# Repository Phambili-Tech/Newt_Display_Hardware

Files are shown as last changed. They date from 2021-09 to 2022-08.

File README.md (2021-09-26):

# Newt

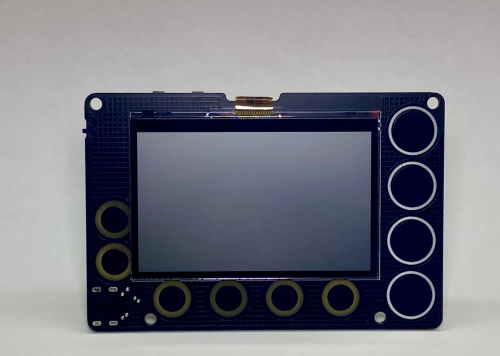
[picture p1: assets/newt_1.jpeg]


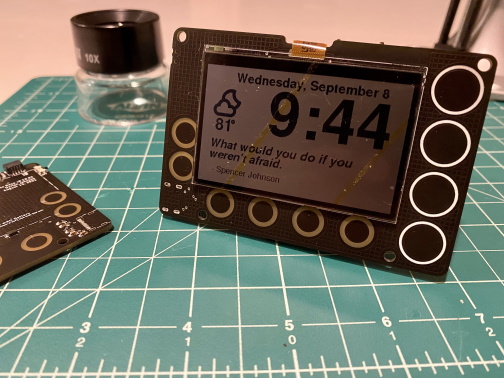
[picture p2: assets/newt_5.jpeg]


The Newt is an always-on, low-powered, mountable display that can be connected to the internet to retrieve weather, calendars, sports scores, todo lists, quotes... really anything that is available on the web! The Newt is powered by an ESP32-S2 microcontroller that can be programmed with Arduino, CircuitPython, and ESP-IDF.

We consider the Newt to be the next evolution of the popular eInk displays that makers love to tinker with. We use a SHARP Memory In Pixel LCD in order to avoid the slow refresh times of eInk. We've added a Real Time Clock to support alarms and timers. Finally, we designed the Newt with battery operation in mind;  every component on the board was chosen for it's ability to operate at low power.

**Lists of product features and/or specifications:**

The Newt is designed to operate for 1-2 months between charges (using a 500 mAH Lipo). The amount of time varies between usage; heavier WiFi usage will more quickly reduce battery charge.

Microcontroller:
- Espressif ESP32-S2-WROVER Module with 4 MB flash and 2 MB PSRAM
- WiFi capable
- Supports Arduino, CircuitPython, and ESP-IDF
- Deep Sleep current as low as 25 uA

Display:
- 2.7 inch 240x400 SHARP Memory In Pixel LCD
- Capable of delivering high-contrast, high-resolution content with ultra-low power consumption
- Reflective mode leverages ambient light to eliminate the need for a backlight

Time Keeping, Timers, and Alarms:
- Micro Crystal RV-3028-C7 Real Time Clock
- Optimized for extreme low power consumption (45 nanoAmps)
- Able to simultaneously manage periodic timer, countdown timer, and alarm
- Hardware interrupt for timers and alarms
- 43 bytes non-volatile user memory, 2 bytes user RAM
- Separate UNIX time counter

Buzzer:
- Speaker/Buzzer with mini class D amplifier on DAC output A0 can play tones or lo-fi audio clips

User Interaction:
- 10 capacitive touch pads
- On/off switch
- Reset and Boot tactile buttons for reprogramming

Power:
- USB Type-C connector for programming, power, and charging
- Low quiescence Voltage Regulator (TOREX XC6220) that can output 1A of current and operate as low as 8 uA.
- JST connector for Lithium-Ion battery
- Battery charging circuity (MCP73831)
- Low Battery indicator (1 uA quiescence current)

PCB and Display dimensions:
- 91 mm x 61mm x 9mm

Software:
- Newt hardware compatible with open-source Arduino libraries for ESP32-S2, Adafruit GFX (fonts), Adafruit Sharp Memory Display (display writing), and RTC RV-3028-C7 (rtc)
- Newt Arduino library and sample programs in progress; will be available on Githib before launch
- Newt CircuitPython libraries and registration on the roadmap (key dependency is the development of CircuitPython library for the RV-3028 real time clock)

Optional Mounting and Desktop Hardware:
- Acrylic Mounting Bracket with magnetic fixtures and expander for "flat" lithium-Ion batteries (up to 2500mAh)
- Putty for non-magnetic adhesion
- Stand for desk or nightstand (made from engineered wood)

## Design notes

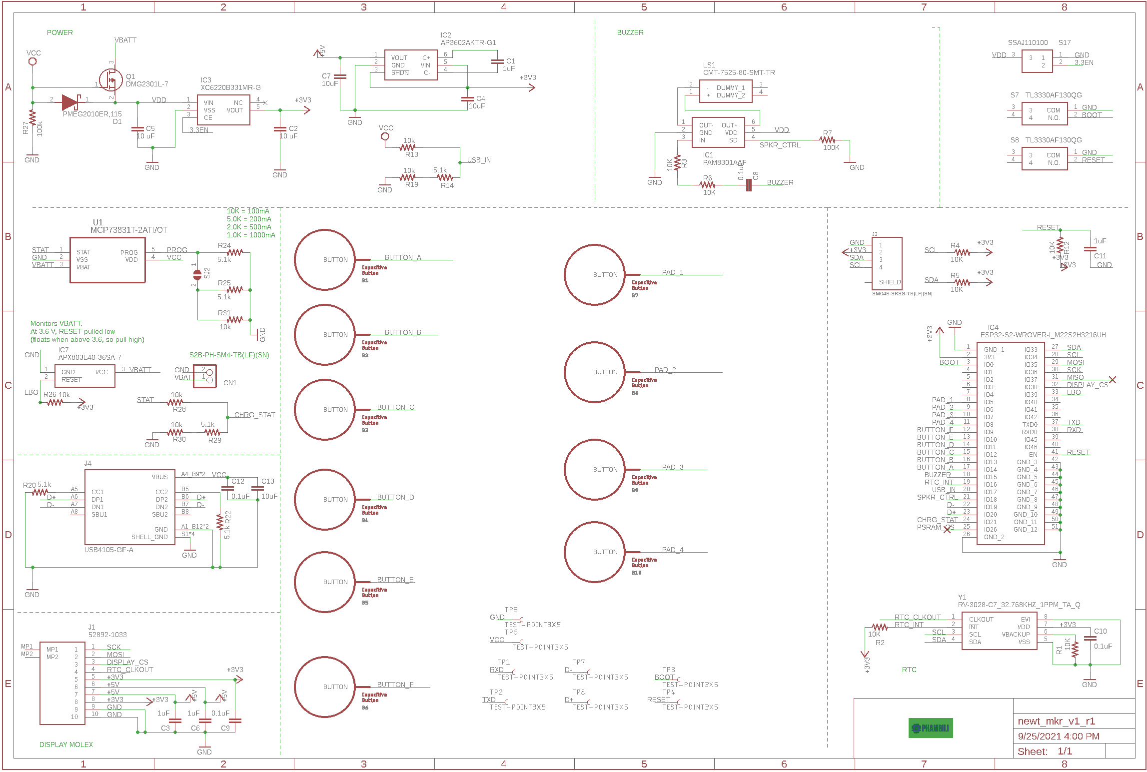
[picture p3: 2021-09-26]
schematic.png

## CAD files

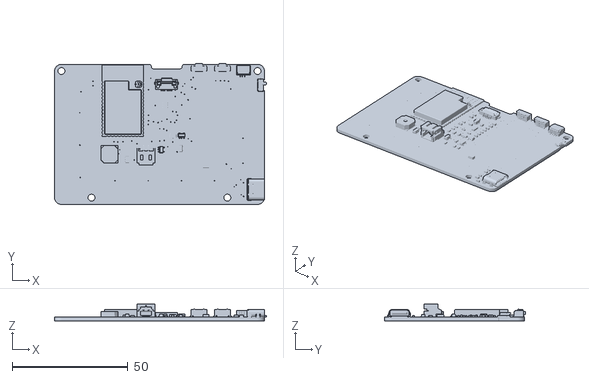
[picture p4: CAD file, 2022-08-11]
3D File Formats/Newt_v1.1_board.stl
91.7 x 60.9 x 7.17

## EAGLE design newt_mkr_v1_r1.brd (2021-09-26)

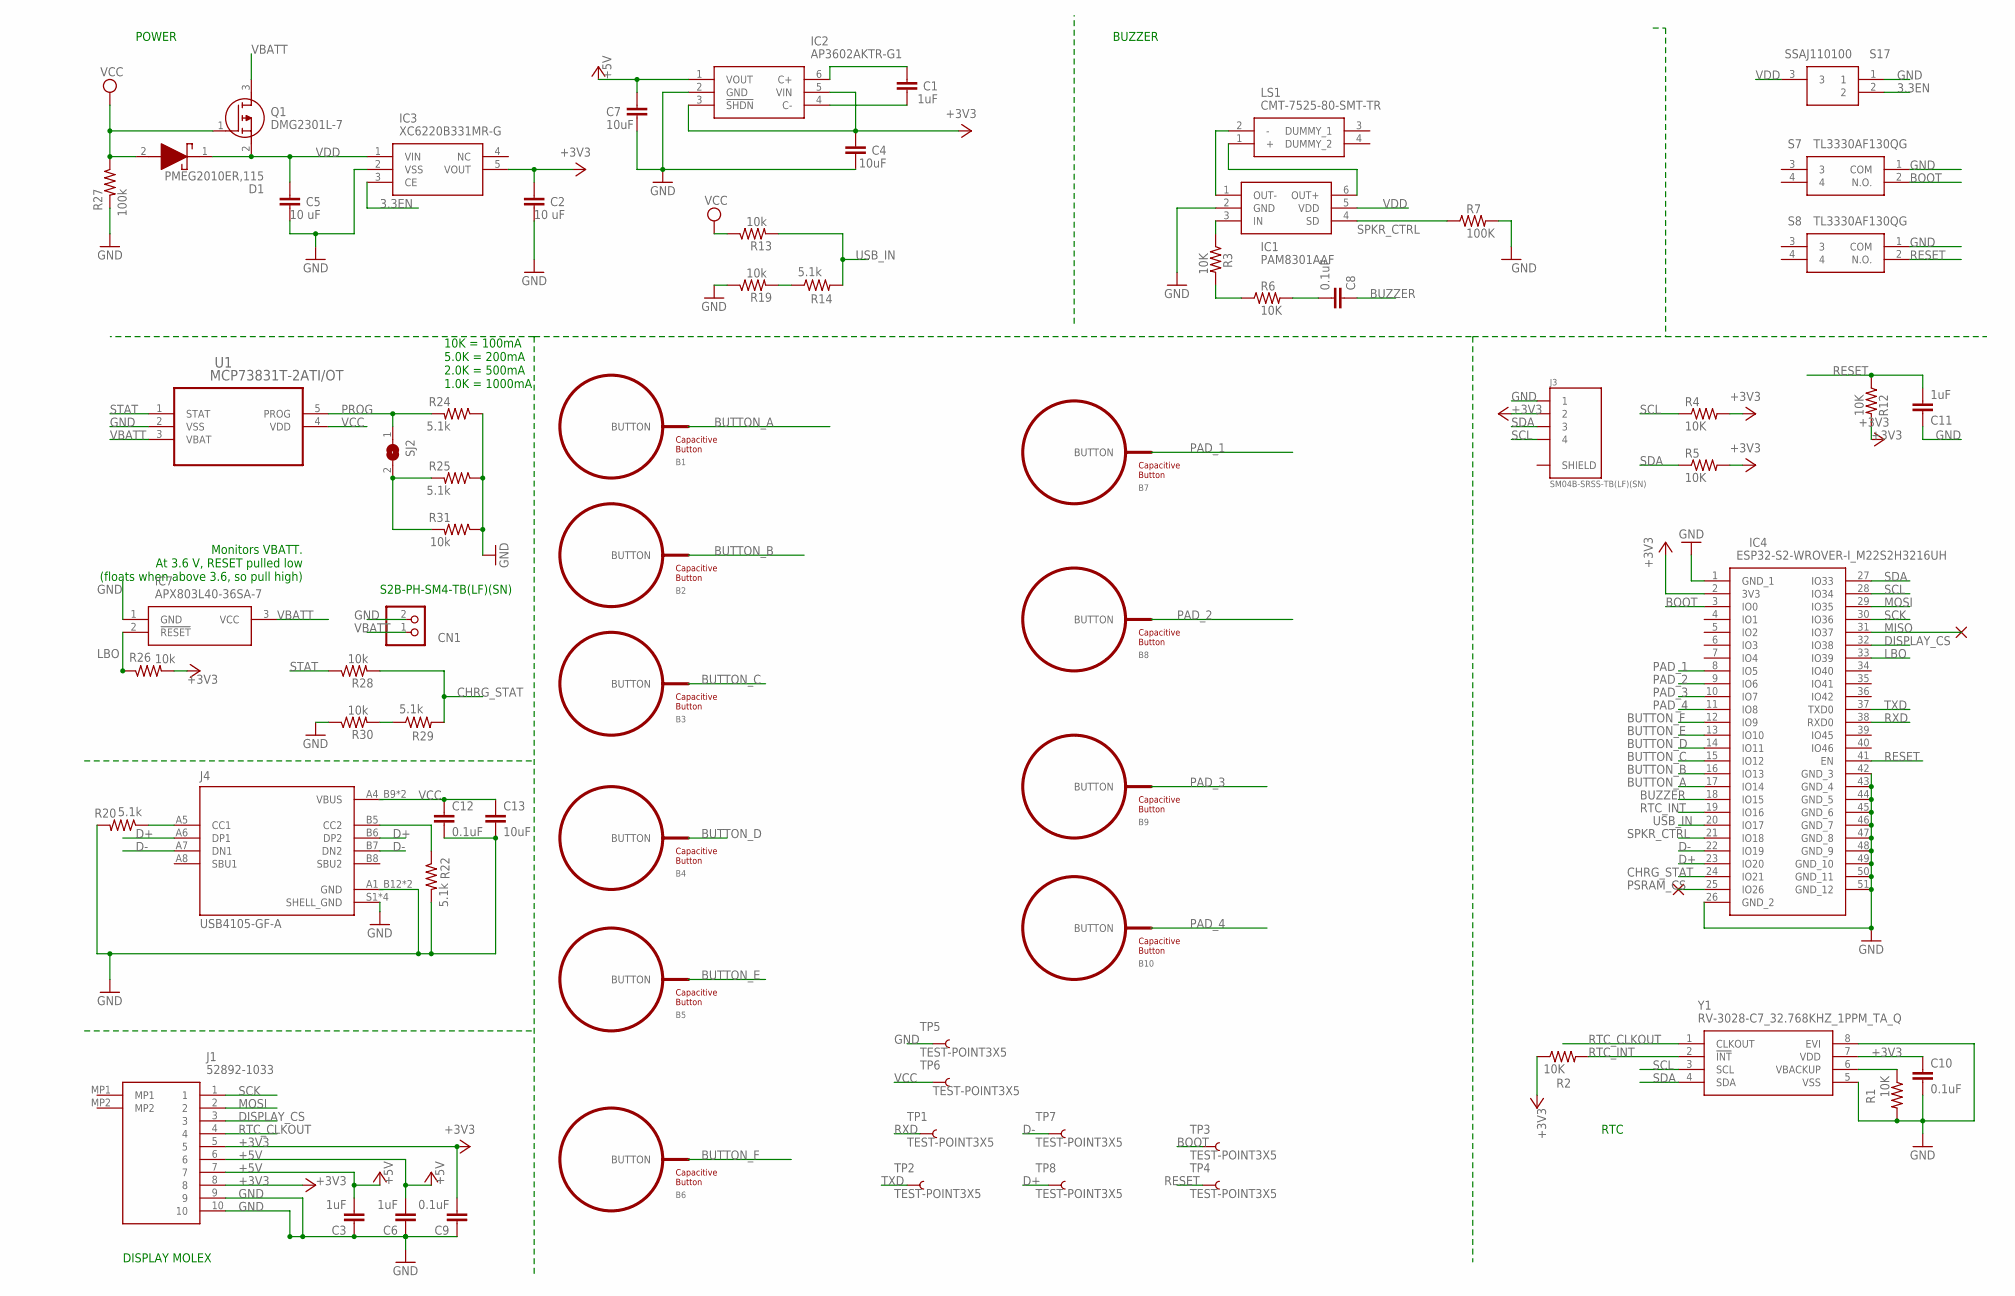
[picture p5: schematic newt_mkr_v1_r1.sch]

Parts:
B1, B2, B3, B4, B5, B6: BUTTON_PASSIVE6MM; BUTTON_PASSIVE_6MM
B7, B8, B9, B10: BUTTON_PASSIVE10MM; BUTTON_PASSIVE_10MM
C1, C3, C6, C11: 1uF; C0603
C2, C5: 10 uF; C0603
C4, C7, C13: 10uF; C0603
C8, C9, C10, C12: 0.1uF; C0603
CN1: JST_2PIN-SMT-RA; JST-PH-2-SMT-RA
D1: PMEG2010ER,115; SODFL3517X110N
IC1: PAM8301AAF; SOT95P280X145-6N
IC2: AP3602AKTR-G1; SOT95P280X145-6N
IC3: XC6220B331MR-G; SOT95P280X130-5N
IC4: ESP32-S2-WROVER-I_M22S2H3216UH; ESP32S2WROVERIM22S2H3216UH3Q0
IC7: APX803L40-36SA-7; SOT96P240X110-3N
J1: 52892-1033; 528921033
J3: SM04B-SRSS-TB(LF)(SN); JST_SM04B-SRSS-TB(LF)(SN)
J4: USB4105-GF-A; GCT_USB4105-GF-A
LS1: CMT-7525-80-SMT-TR; CMT752580SMTTR
Q1: DMG2301L-7; SOT96P240X110-3N
R1, R2, R3, R4, R5, R6, R12: 10K; R0603
R7: 100K; R0603
R13, R19, R26, R28, R30, R31: 10k; R0603
R14, R20, R22, R24, R25, R29: 5.1k; R0603
R27: 100k; R0603
S7, S8: TL3330AF130QG
S17: SSAJ110100; SSAJ110100_1
SJ2: MICROBUILDER_SOLDERJUMPERCLOSED; MICROBUILDER_SOLDERJUMPER_CLOSEDWIRE
TP1, TP2, TP3, TP4, TP5, TP6, TP7, TP8: TEST-POINT3X5; PAD.03X.05
U1: MCP73831T-2ATI/OT; SOT95P300X145-5N
Y1: RV-3028-C7_32.768KHZ_1PPM_TA_Q; RV-8803-C7

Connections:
3.3EN: IC3.3 (CE), S17.2
+3V3: C2.2, C4.2, C9.2, C10.1, IC2.3 (!SHDN), IC2.5 (VIN), IC3.5 (VOUT), IC4.2 (3V3), J1.5, J1.8, J3.2, R2.1, R4.2, R5.2, R12.2, R26.2, Y1.7 (VDD)
+5V: C3.2, C6.2, C7.2, IC2.1 (VOUT), J1.6, J1.7
BOOT: IC4.3 (IO0), S7.2 (N.O.), TP3.P$1
BUTTON_A: B1.BUTTON, IC4.17 (IO14)
BUTTON_B: B2.BUTTON, IC4.16 (IO13)
BUTTON_C: B3.BUTTON, IC4.15 (IO12)
BUTTON_D: B4.BUTTON, IC4.14 (IO11)
BUTTON_E: B5.BUTTON, IC4.13 (IO10)
BUTTON_F: B6.BUTTON, IC4.12 (IO9)
BUZZER: C8.1, IC4.18 (IO15)
CC2: J4.B5 (CC2), R22.1
CHRG_STAT: IC4.24 (IO21), R28.2, R29.2
D+: IC4.23 (IO20), J4.A6 (DP1), J4.B6 (DP2), TP8.P$1
D-: IC4.22 (IO19), J4.A7 (DN1), J4.B7 (DN2), TP7.P$1
DISPLAY_CS: IC4.32 (IO38), J1.3
GND: C2.1, C3.1, C4.1, C5.1, C6.1, C7.1, C9.1, C10.2, C11.1, C12.2, C13.2, CN1.2 (1), IC1.2 (GND), IC2.2 (GND), IC3.2 (VSS), IC4.1 (GND_1), IC4.26 (GND_2), IC4.42 (GND_3), IC4.43 (GND_4), IC4.44 (GND_5), IC4.45 (GND_6), IC4.46 (GND_7), IC4.47 (GND_8), IC4.48 (GND_9), IC4.49 (GND_10), IC4.50 (GND_11), IC4.51 (GND_12), IC7.1 (GND), J1.9, J1.10, J3.1, J4.A1_B12 (GND), J4.B1_A12 (GND), J4.S1 (SHELL_GND), J4.S2 (SHELL_GND), J4.S3 (SHELL_GND), J4.S4 (SHELL_GND), R1.2, R7.2, R19.1, R20.2, R22.2, R24.1, R25.1, R27.2, R30.1, R31.1, S7.1 (COM), S8.1 (COM), S17.1, TP5.P$1, U1.2 (VSS), Y1.5 (VSS), Y1.8 (EVI)
LBO: IC4.33 (IO39), IC7.2 (!RESET), R26.1
MISO: IC4.31 (IO37)
MOSI: IC4.29 (IO35), J1.2
unnamed: IC1.6 (OUT+), LS1.1 (+)
unnamed: IC1.1 (OUT-), LS1.2 (-)
unnamed: R1.1, Y1.6 (VBACKUP)
unnamed: R14.1, R19.2
unnamed: C1.2, IC2.6 (C+)
unnamed: C1.1, IC2.4 (C-)
unnamed: IC1.3 (IN), R3.1
unnamed: R29.1, R30.2
unnamed: R25.2, R31.2, SJ2.2
unnamed: R3.2, R6.1
unnamed: C8.2, R6.2
unnamed: J4.A5 (CC1), R20.1
PAD_1: B7.BUTTON, IC4.8 (IO5)
PAD_2: B8.BUTTON, IC4.9 (IO6)
PAD_3: B9.BUTTON, IC4.10 (IO7)
PAD_4: B10.BUTTON, IC4.11 (IO8)
PROG: R24.2, SJ2.1, U1.5 (PROG)
PSRAM_CS: IC4.25 (IO26)
RESET: C11.2, IC4.41 (EN), R12.1, S8.2 (N.O.), TP4.P$1
RTC_CLKOUT: J1.4, Y1.1 (CLKOUT)
RTC_INT: IC4.19 (IO16), R2.2, Y1.2 (!INT)
RXD: IC4.38 (RXD0), TP1.P$1
SCK: IC4.30 (IO36), J1.1
SCL: IC4.28 (IO34), J3.4, R4.1, Y1.3 (SCL)
SDA: IC4.27 (IO33), J3.3, R5.1, Y1.4 (SDA)
SPKR_CTRL: IC1.4 (SD), IC4.21 (IO18), R7.1
STAT: R28.1, U1.1 (STAT)
TXD: IC4.37 (TXD0), TP2.P$1
USB_IN: IC4.20 (IO17), R13.2, R14.2
VBATT: CN1.1 (2), IC7.3 (VCC), Q1.3 (D), U1.3 (VBAT)
VCC: C12.1, C13.1, D1.2 (A), J4.A4_B9 (VBUS), J4.B4_A9 (VBUS), Q1.1 (G), R13.1, R27.1, TP6.P$1, U1.4 (VDD)
VDD: C5.2, D1.1 (K), IC1.5 (VDD), IC3.1 (VIN), Q1.2 (S), S17.3

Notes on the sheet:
POWER
DISPLAY MOLEX
RTC
Monitors VBATT. At 3.6 V, RESET pulled low (floats when above 3.6, so pull high)
S2B-PH-SM4-TB(LF)(SN)‎
10K = 100mA 5.0K = 200mA 2.0K = 500mA 1.0K = 1000mA
BUZZER

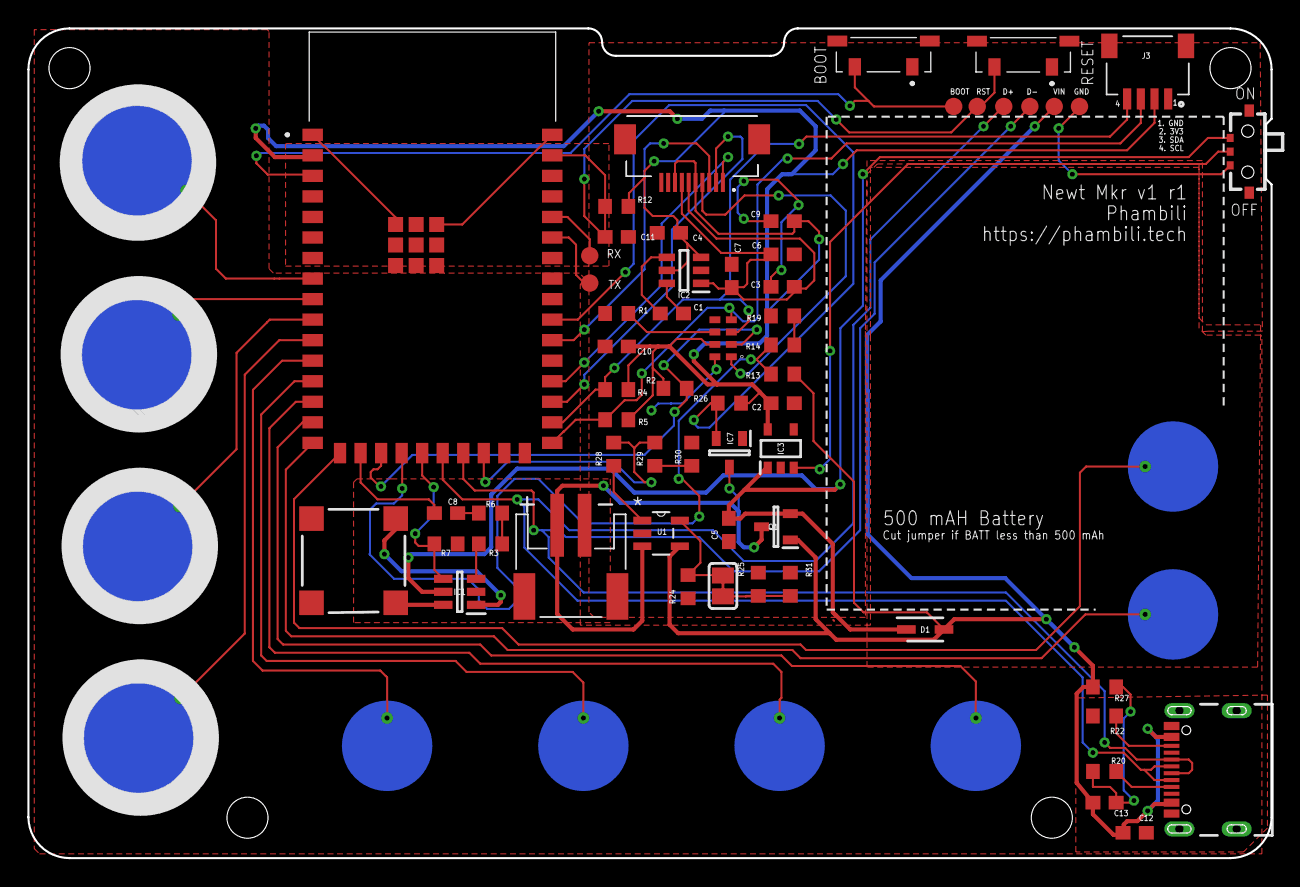
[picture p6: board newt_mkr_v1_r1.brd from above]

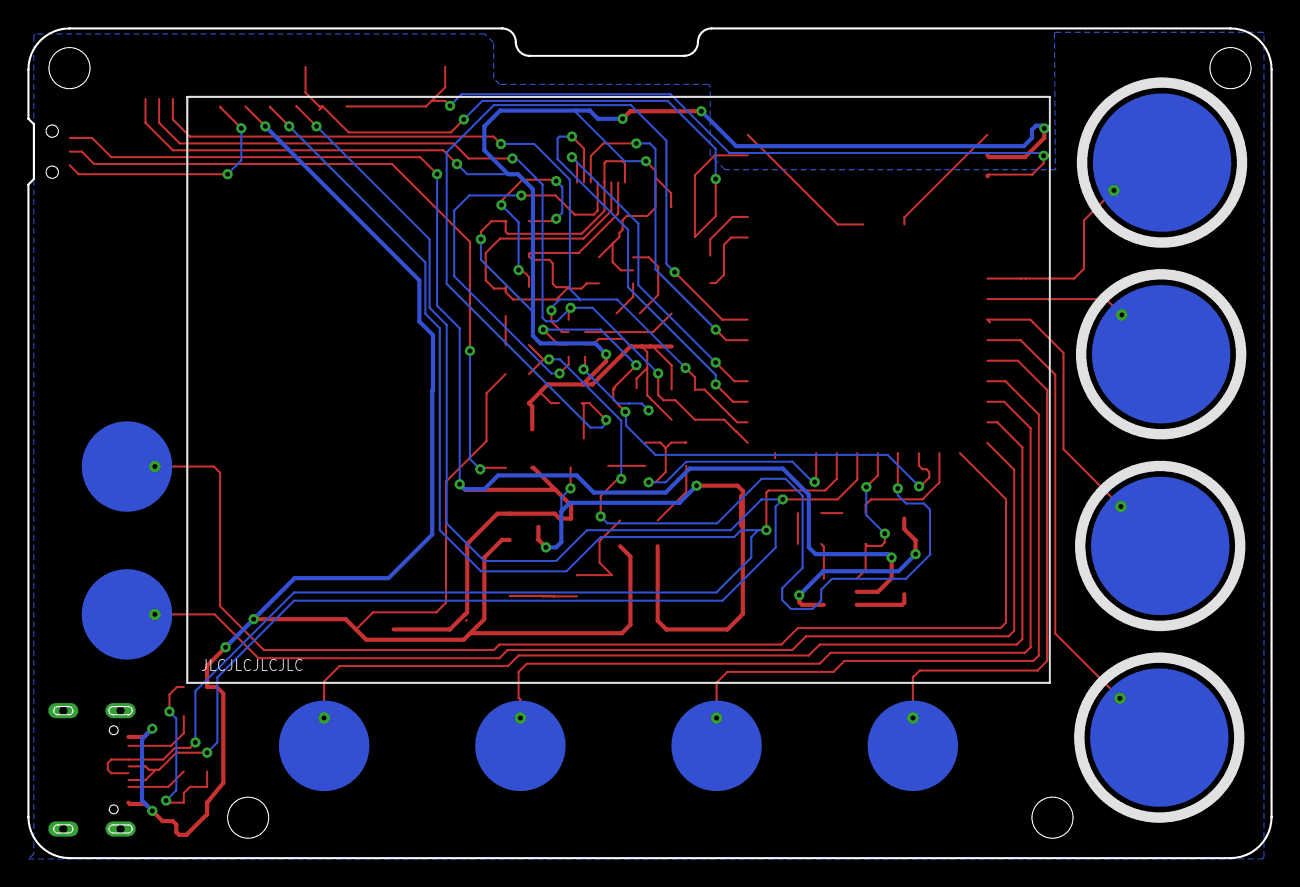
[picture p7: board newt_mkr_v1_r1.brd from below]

Board: 2 copper layers, 90.8 x 60.6 mm, 70 parts (10 on the bottom side), 50 nets.

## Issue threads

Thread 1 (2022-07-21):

Stand assembly guide

andypiper, 2022-07-21:
Is there any information about how to assemble the wooden laser cut stand? I’m not clear whether I should be breaking anything out from the main sheet?

andypiper, 2022-07-21:
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

Adding this image for anyone else who wonders how it fits together - the 4 larger silver magnetic feet are not needed with the desk stand.

I found it easiest to fit the black struts while the wooden frame lay flat; turn it over to add the four rubber feet in each corner; and screw the Newt board on to the front, before lifting it forward.

You’ll want to fit the battery before mounting the board onto the stand.

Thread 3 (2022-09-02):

investigate Q1 orientation in the schematic/layout

slamkal, 2022-09-02:
I don't think the circuit is working as intended .   Believe the drain and source are swapped causing this fet just to act like a diode.

slamkal, 2022-09-06:
after further review I think it works fine.   as configured the body diode will allow a current path from VBATT to VDD.   while under battery only operation, rising VDD makes the gate negative with respect to the source, which enhances the fetThe fet inherently turns on, shorting out the parasitic body diode through the D-S channel.       I think also the configuration as shown allows for inherent reverse battery protection, as well as blocks the charging path from the USB to VBAT.   Pretty sneaky!

Closed 2022-09-06.

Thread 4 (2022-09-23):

Q1

GertLauritsen, 2022-09-23:
Source and drain on Q1 is wrong. In this config you are just using the fet as a diode. If you flip it, then then fet turns on, then vcc is low.

andypiper, 2022-09-23:
This seems to be a duplicate of #3 and that may answer what you are observing.

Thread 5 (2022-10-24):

Default battery charge current and changing via pads?

andyshinn, 2022-10-24:
If i am reading the schematic correctly, it looks like the default is 10k (100mA) as `SJ2` is connected by default? If I cut the trace between the pads then it would be 200mA because the least resistance would be 5.1k? Is this correct?

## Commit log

2021-09-26 added eagle files
    [newt_mkr__v1_r1.brd, newt_mkr_v1_r1.sch]
2021-09-26 added schematic in png
2021-09-26 Rename eagle board
    [newt_mkr_v1_r1.brd]
2021-09-26 added Fusion 360 archive
    [newt_mkr__v1_r1.brd]
2022-08-11 Step, Obj, and STL files for Newt Board
    [Newt_v1.1_board.stl]

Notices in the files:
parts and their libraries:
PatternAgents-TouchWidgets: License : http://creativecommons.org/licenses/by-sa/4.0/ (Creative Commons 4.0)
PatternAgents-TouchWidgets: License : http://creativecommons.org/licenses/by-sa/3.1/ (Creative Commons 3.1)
